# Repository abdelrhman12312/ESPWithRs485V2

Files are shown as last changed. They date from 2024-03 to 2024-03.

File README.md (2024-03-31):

# ESPWithRs485V2

you can view the pcb here in your browser 
https://kicanvas.org/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

iot master

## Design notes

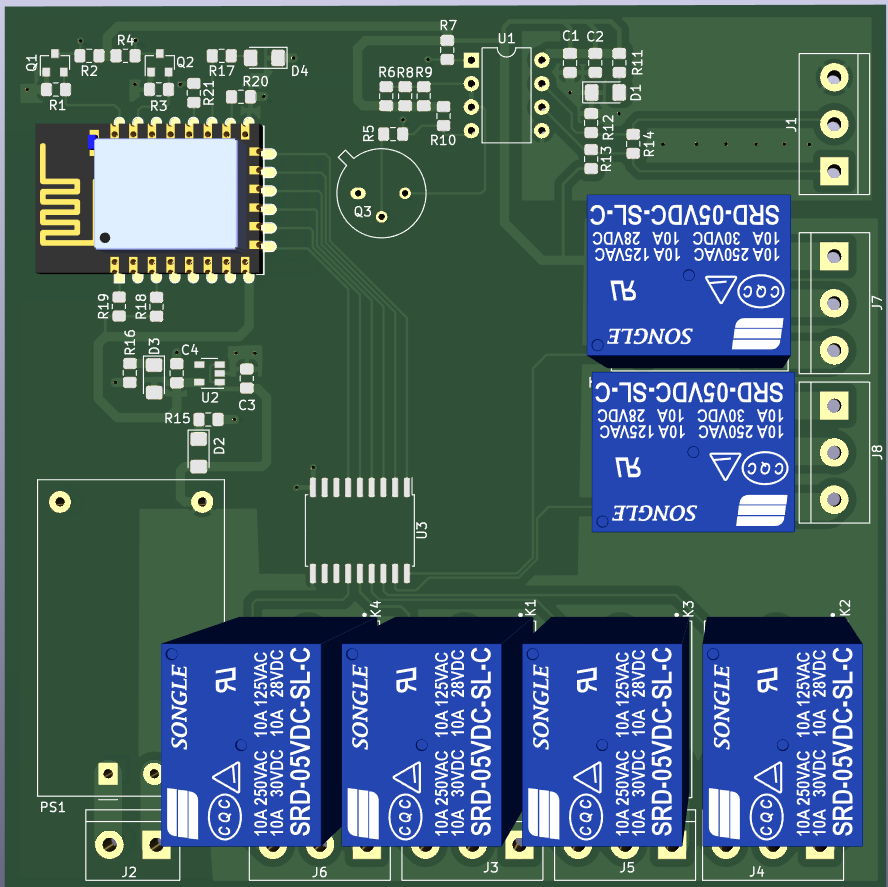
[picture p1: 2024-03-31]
iot master/png/Screenshot 2022-09-27 210828.png

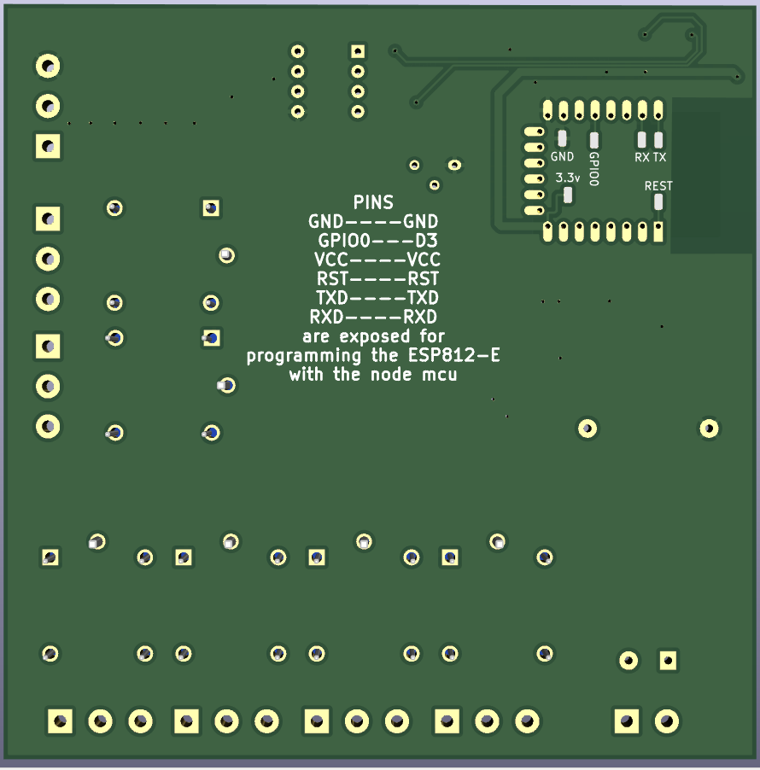
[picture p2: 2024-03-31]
iot master/png/Screenshot 2022-09-27 210906.png

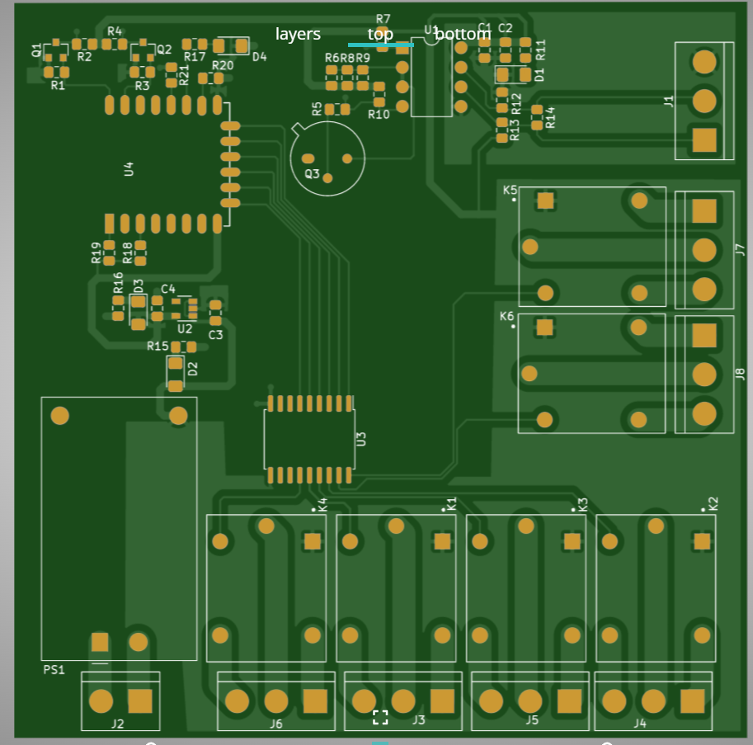
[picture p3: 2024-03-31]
iot master/png/GerberRender.png

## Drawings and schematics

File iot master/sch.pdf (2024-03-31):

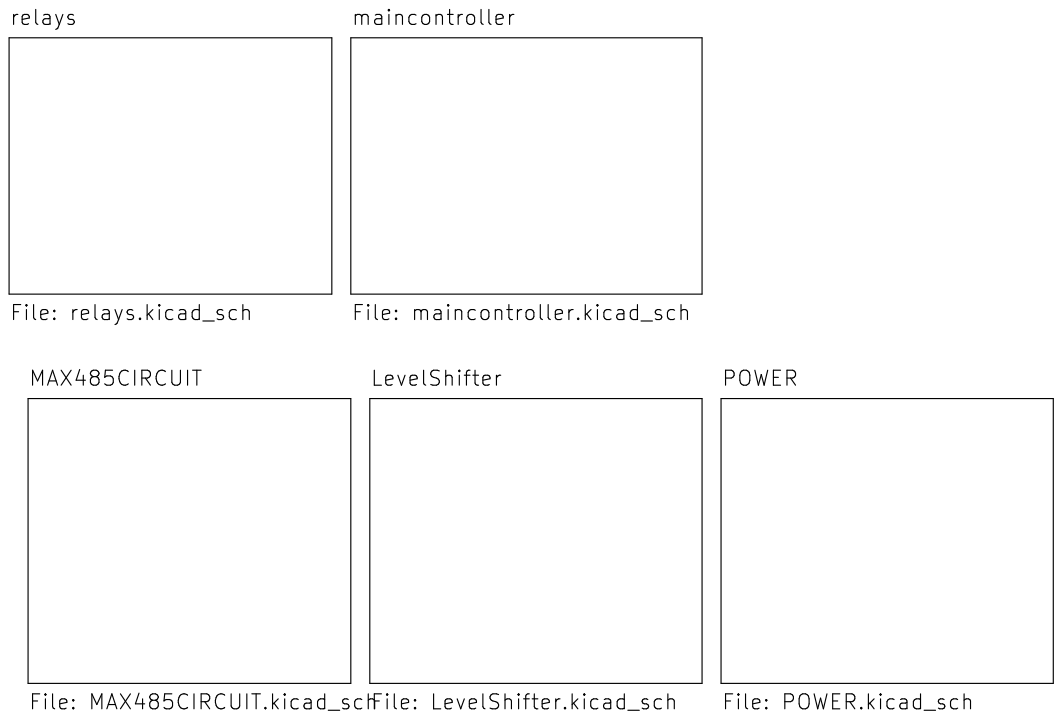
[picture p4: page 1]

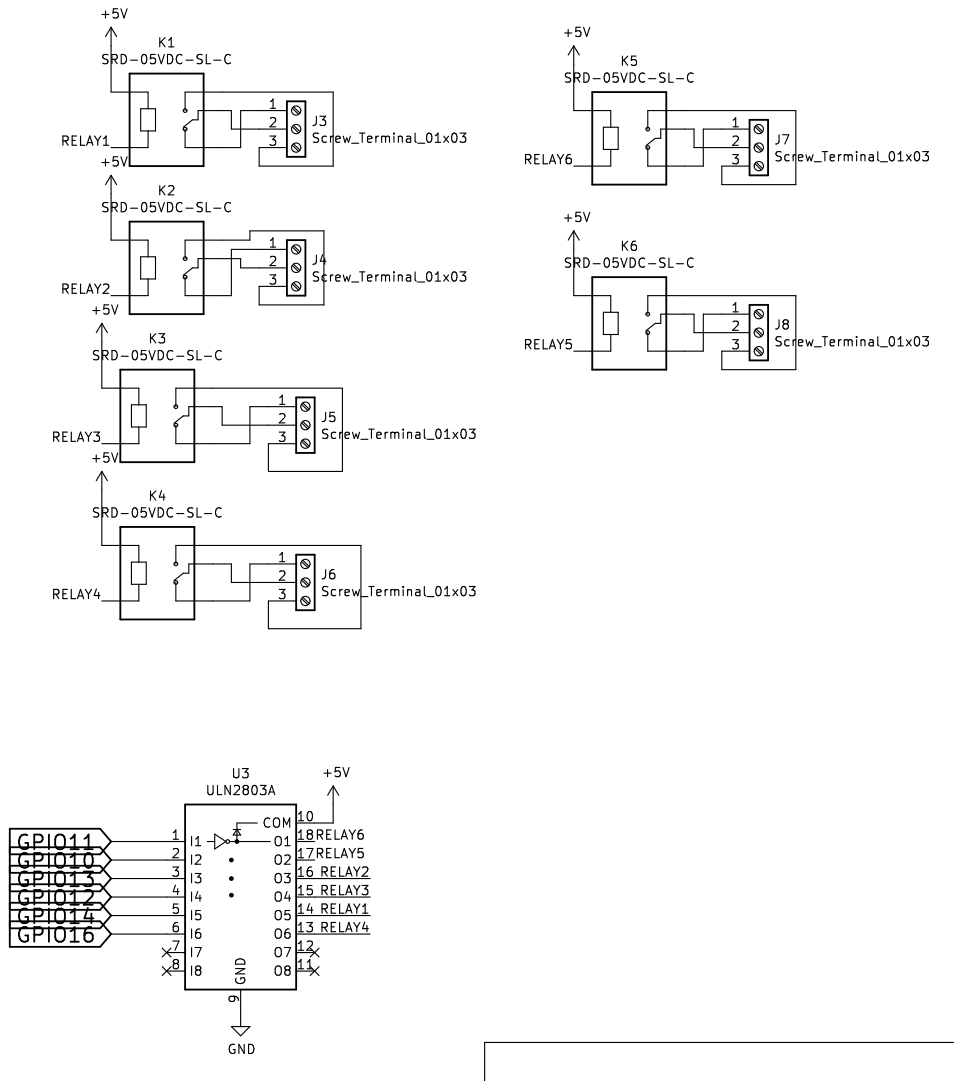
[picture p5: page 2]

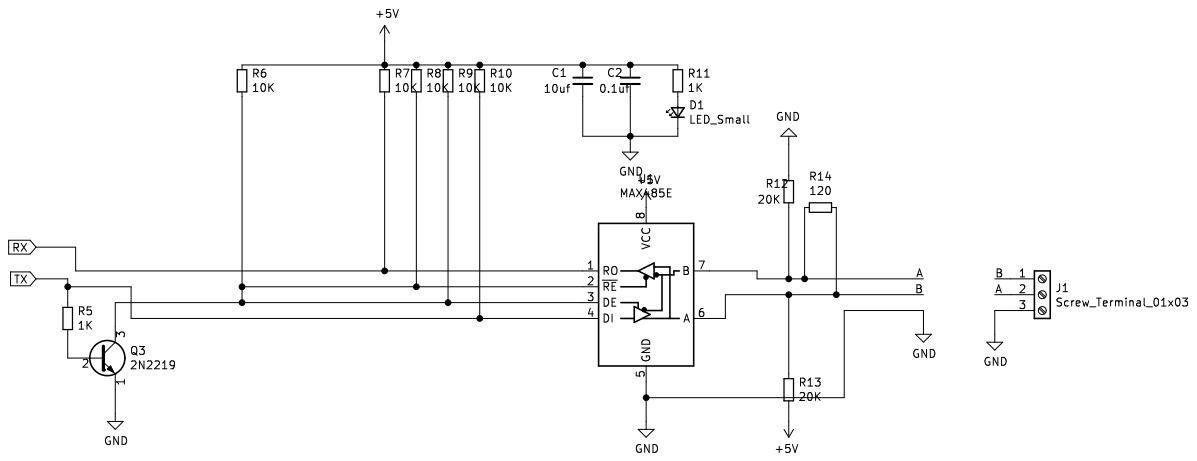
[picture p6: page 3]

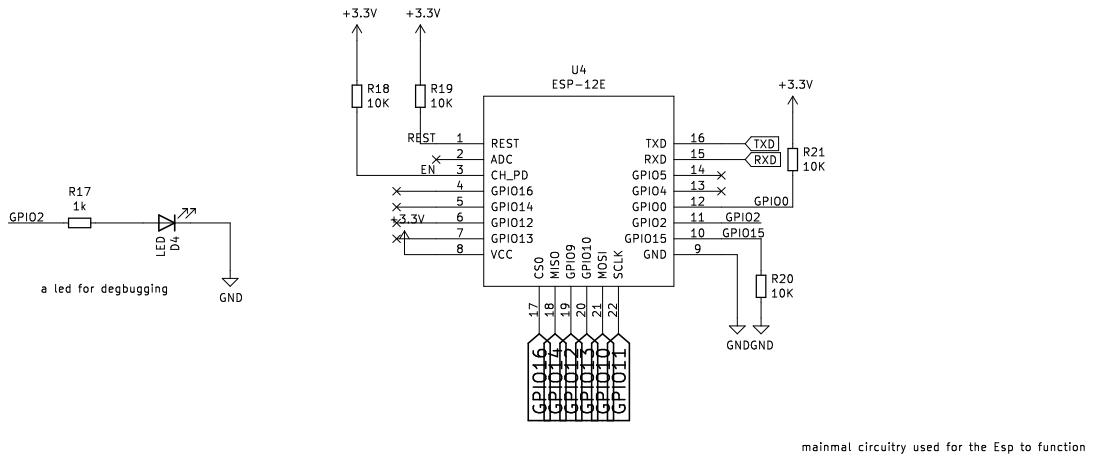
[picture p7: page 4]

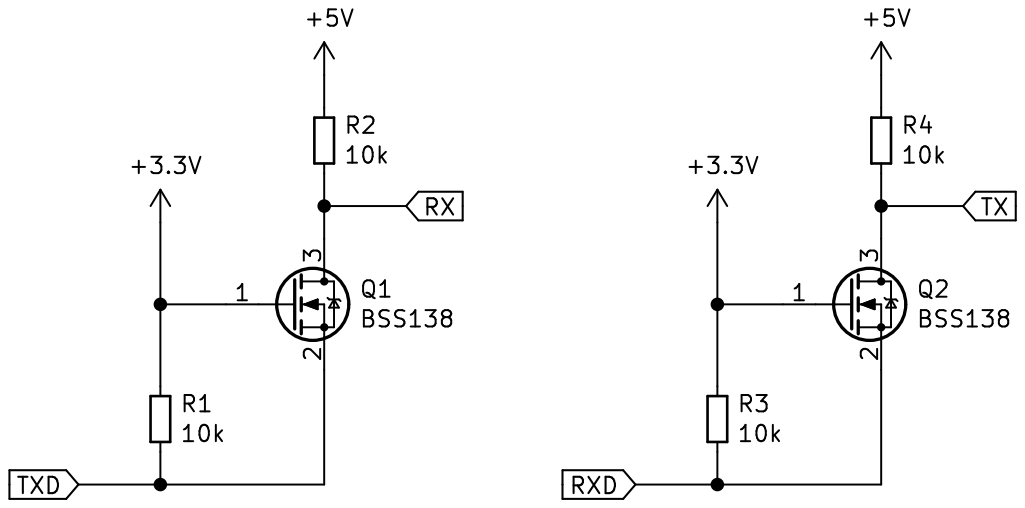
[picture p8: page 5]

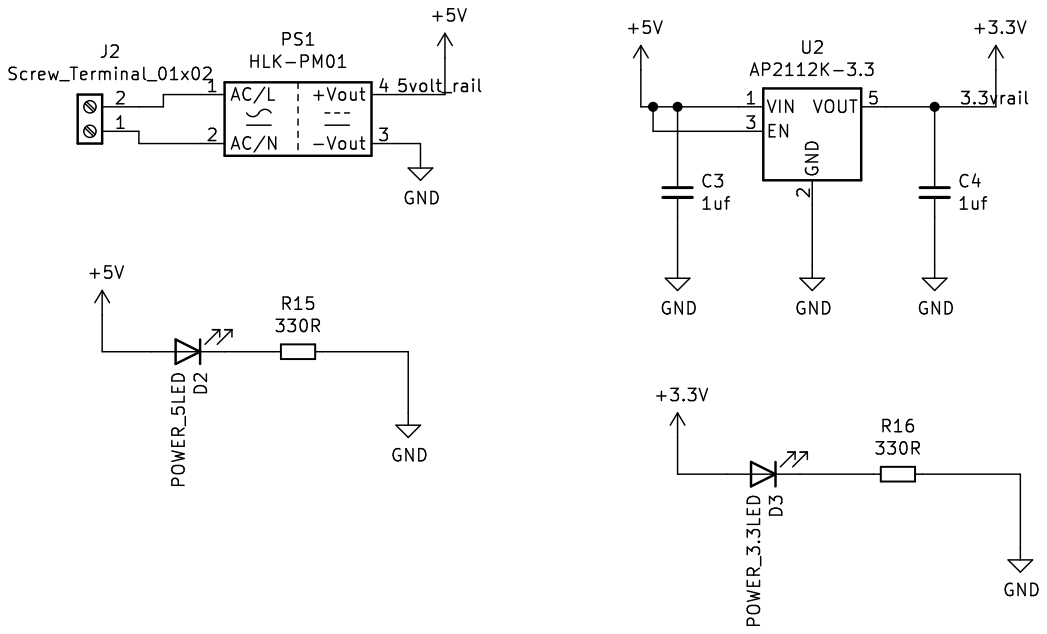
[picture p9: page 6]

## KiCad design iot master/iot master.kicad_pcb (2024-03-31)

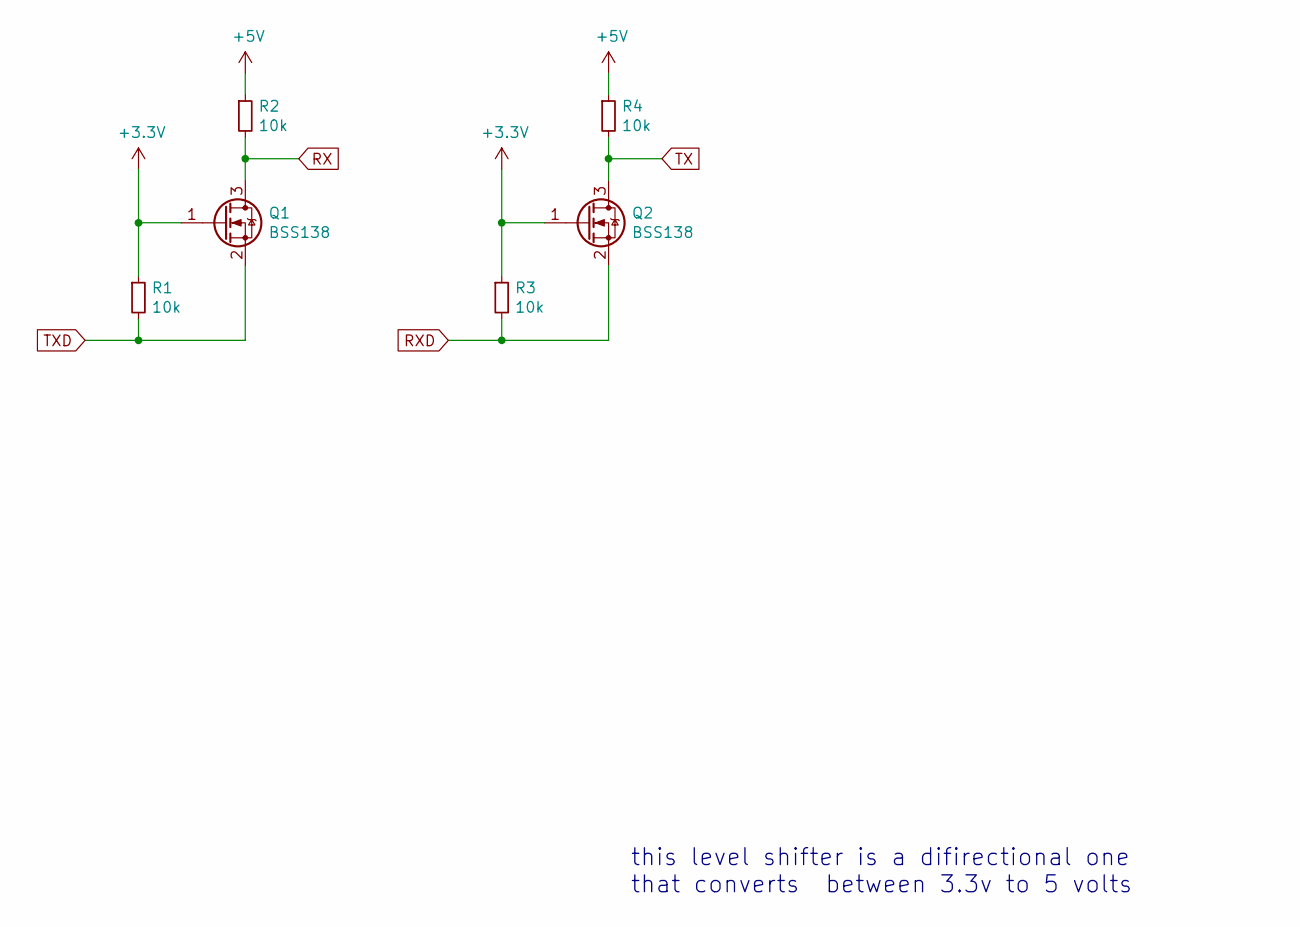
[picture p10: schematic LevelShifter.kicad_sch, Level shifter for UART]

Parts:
Q1, Q2: BSS138; SOT-23
R1, R2, R3, R4: 10k; R_0805_2012Metric_Pad1.15x1.40mm_HandSolder

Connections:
+3V3: Q1.1 (G), Q2.1 (G), R1.1, R3.1; also elsewhere on the board
+5V: R2.1, R4.1; also elsewhere on the board
RX: Q1.3 (D), R2.2; also elsewhere on the board
RXD: Q2.2 (S), R3.2; also elsewhere on the board
TX: Q2.3 (D), R4.2; also elsewhere on the board
TXD: Q1.2 (S), R1.2; also elsewhere on the board

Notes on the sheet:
this level shifter is a difirectional one that converts between 3.3v to 5 volts

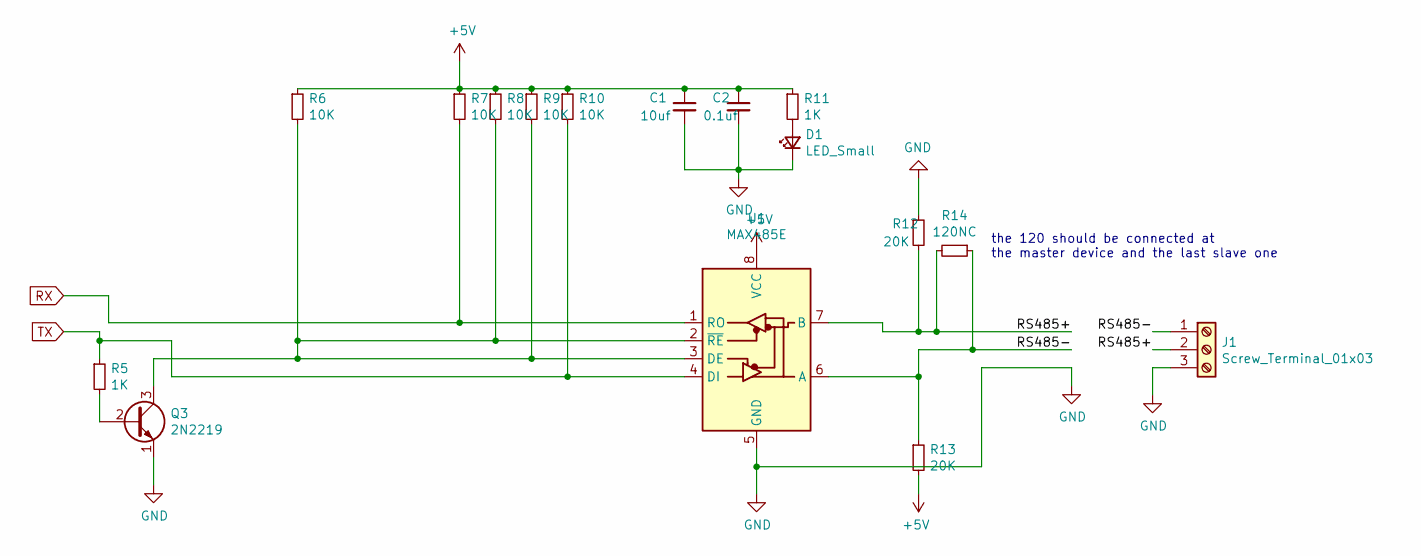
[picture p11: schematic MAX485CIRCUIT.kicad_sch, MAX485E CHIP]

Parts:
C1: 10uf; C_0805_2012Metric_Pad1.15x1.40mm_HandSolder
C2: 0.1uf; C_0805_2012Metric_Pad1.15x1.40mm_HandSolder
D1: LED_Small; LED_1206_3216Metric_Pad1.42x1.75mm_HandSolder
J1: Screw_Terminal_01x03; TerminalBlock_bornier-3_P5.08mm
Q3: 2N2219; TO-39-3
R5, R11: 1K; R_0805_2012Metric_Pad1.15x1.40mm_HandSolder
R6, R7, R8, R9, R10: 10K; R_0805_2012Metric_Pad1.15x1.40mm_HandSolder
R12, R13: 20K; R_0805_2012Metric_Pad1.15x1.40mm_HandSolder
R14: 120NC; R_0805_2012Metric_Pad1.15x1.40mm_HandSolder
U1: MAX485E; DIP-8_W7.62mm

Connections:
+5V: C1.1, C2.1, R6.1, R7.1, R8.1, R9.1, R10.1, R11.1, R13.2, U1.8 (VCC); also elsewhere on the board
/MAX485CIRCUIT/RS485+: J1.2, R12.2, R14.2, U1.7 (B)
/MAX485CIRCUIT/RS485-: J1.1, R13.1, R14.1, U1.6 (A)
GND: C1.2, C2.2, D1.1 (K), J1.3, Q3.1 (E), R12.1, U1.5 (GND); also elsewhere on the board
unnamed: D1.2 (A), R11.2
unnamed: Q3.2 (B), R5.2
unnamed: Q3.3 (C), R6.2, R8.2, R9.2, U1.2 (~RE), U1.3 (DE)
RX: R7.2, U1.1 (RO); also elsewhere on the board
TX: R5.1, R10.2, U1.4 (DI); also elsewhere on the board

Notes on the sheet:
the 120 should be connected at the master device and the last slave one

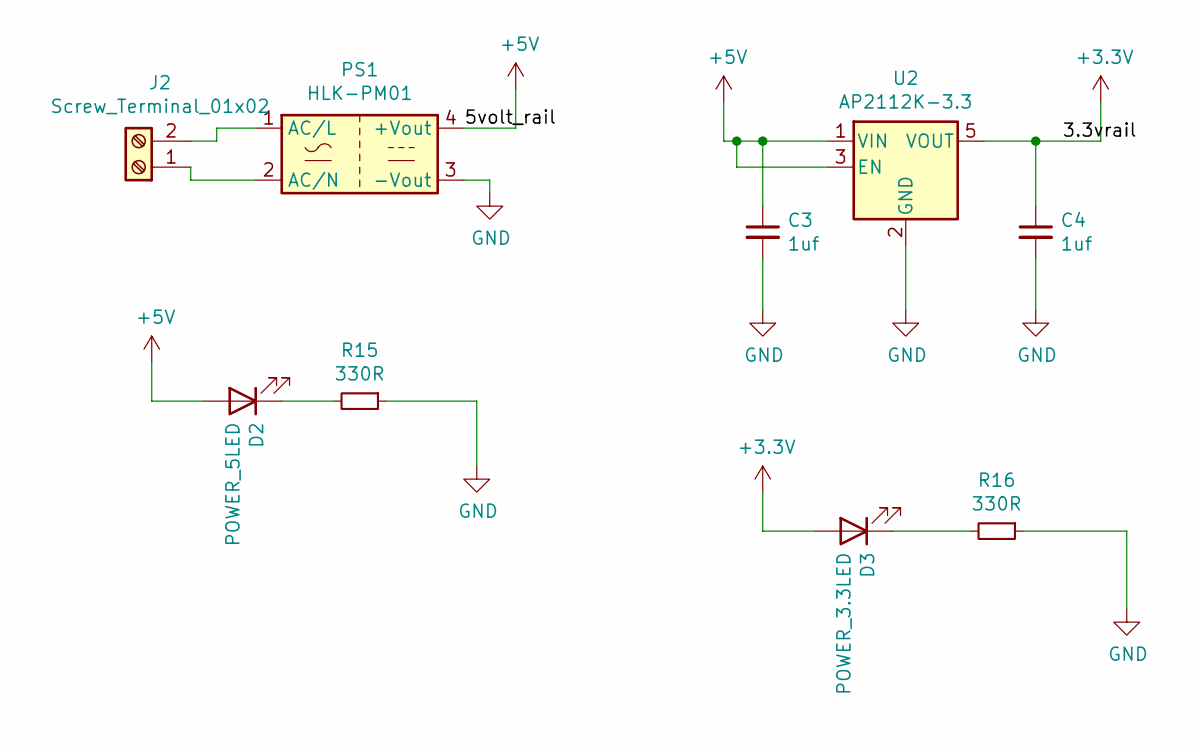
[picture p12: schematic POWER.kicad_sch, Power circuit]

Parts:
C3, C4: 1uf; R_0805_2012Metric_Pad1.15x1.40mm_HandSolder
D2: POWER_5LED; LED_1206_3216Metric_Pad1.42x1.75mm_HandSolder
D3: POWER_3.3LED; LED_1206_3216Metric_Pad1.42x1.75mm_HandSolder
J2: Screw_Terminal_01x02; TerminalBlock_bornier-2_P5.08mm
PS1: HLK-PM01; Converter_ACDC_HiLink_HLK-PMxx
R15, R16: 330R; R_0805_2012Metric_Pad1.15x1.40mm_HandSolder
U2: AP2112K-3.3; SOT-23-5

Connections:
+3V3: C4.1, D3.2 (A), U2.5 (VOUT); also elsewhere on the board
+5V: C3.1, D2.2 (A), PS1.4 (+Vout), U2.1 (VIN), U2.3 (EN); also elsewhere on the board
GND: C3.2, C4.2, PS1.3 (-Vout), R15.1, R16.1, U2.2 (GND); also elsewhere on the board
unnamed: D2.1 (K), R15.2
unnamed: D3.1 (K), R16.2
unnamed: J2.1, PS1.2 (AC/N)
unnamed: J2.2, PS1.1 (AC/L)

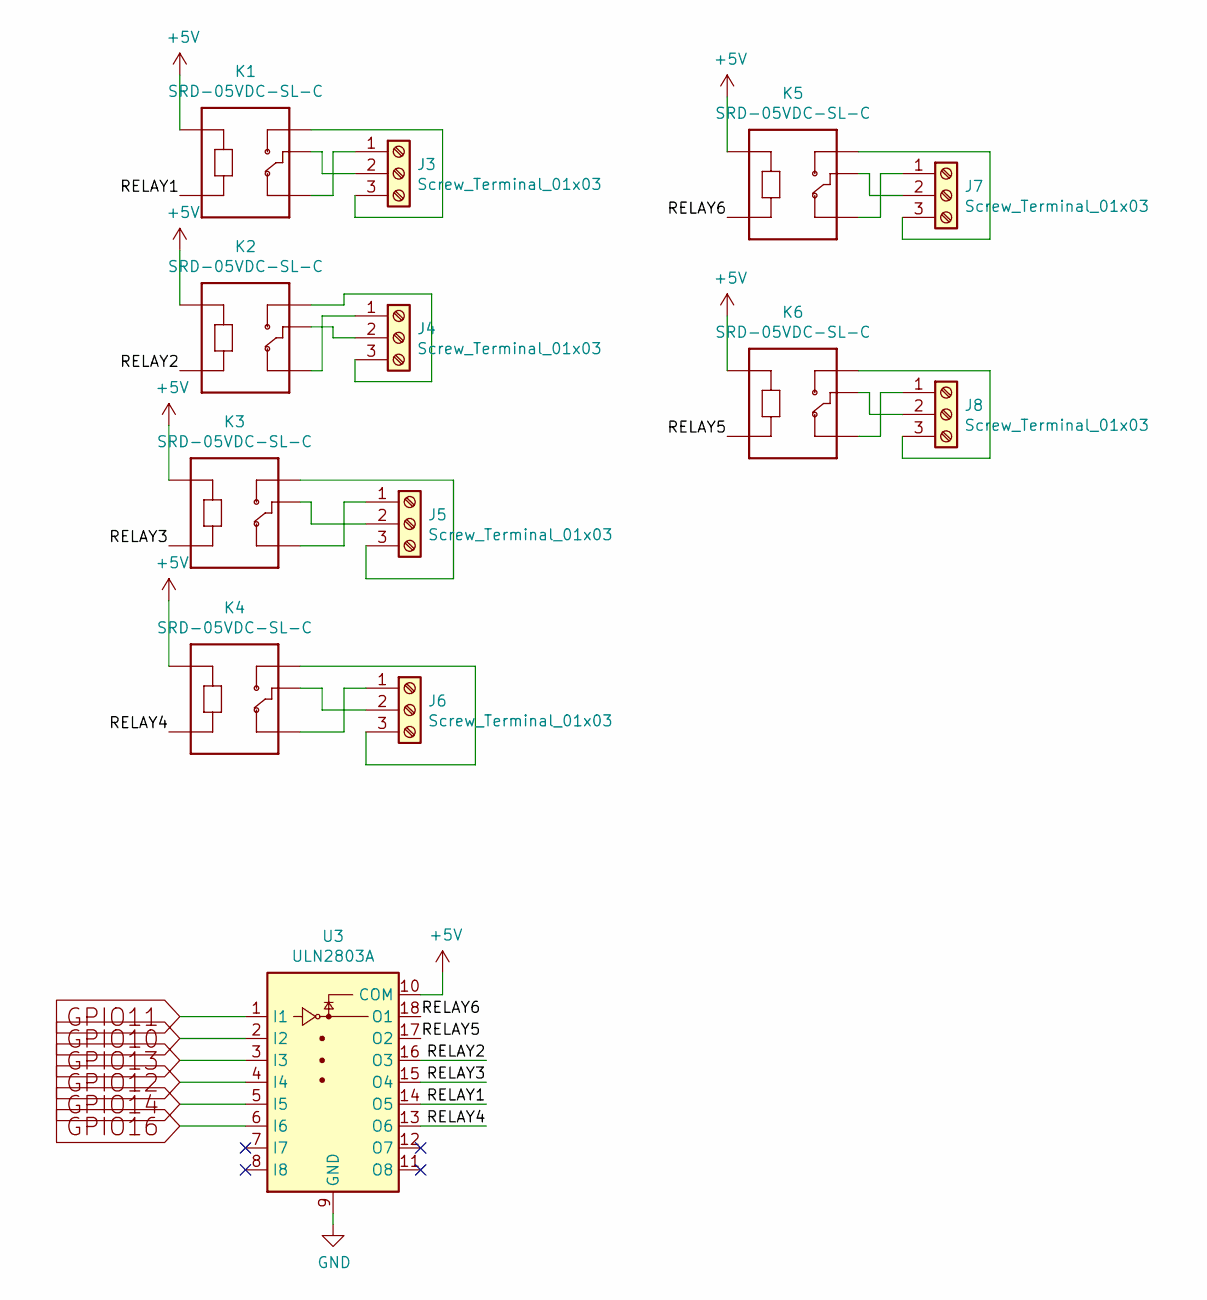
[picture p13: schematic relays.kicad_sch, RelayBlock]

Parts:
J3, J4, J5, J6, J7, J8: Screw_Terminal_01x03; TerminalBlock_bornier-3_P5.08mm
K1, K2, K3, K4, K5, K6: SRD-05VDC-SL-C; RELAY_SRD-05VDC-SL-C
U3: ULN2803A; DIP-18_W7.62mm

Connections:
+5V: K1.A1, K2.A1, K3.A1, K4.A1, K5.A1, K6.A1, U3.10 (COM); also elsewhere on the board
/relays/RELAY1: K1.A2, U3.14 (O5)
/relays/RELAY2: K2.A2, U3.16 (O3)
/relays/RELAY3: K3.A2, U3.15 (O4)
/relays/RELAY4: K4.A2, U3.13 (O6)
/relays/RELAY5: K6.A2, U3.17 (O2)
/relays/RELAY6: K5.A2, U3.18 (O1)
GND: U3.9 (GND); also elsewhere on the board
GPIO10: U3.2 (I2); also elsewhere on the board
GPIO11: U3.1 (I1); also elsewhere on the board
GPIO12: U3.4 (I4); also elsewhere on the board
GPIO13: U3.3 (I3); also elsewhere on the board
GPIO14: U3.5 (I5); also elsewhere on the board
GPIO16: U3.6 (I6); also elsewhere on the board
unnamed: J3.1, K1.NC
unnamed: J3.2, K1.COM
unnamed: J3.3, K1.NO
unnamed: J4.1, K2.NC
unnamed: J4.2, K2.COM
unnamed: J4.3, K2.NO
unnamed: J5.1, K3.NC
unnamed: J5.2, K3.COM
unnamed: J5.3, K3.NO
unnamed: J6.1, K4.NC
unnamed: J6.2, K4.COM
unnamed: J6.3, K4.NO
unnamed: J7.1, K5.NC
unnamed: J7.2, K5.COM
unnamed: J7.3, K5.NO
unnamed: J8.1, K6.NC
unnamed: J8.2, K6.COM
unnamed: J8.3, K6.NO

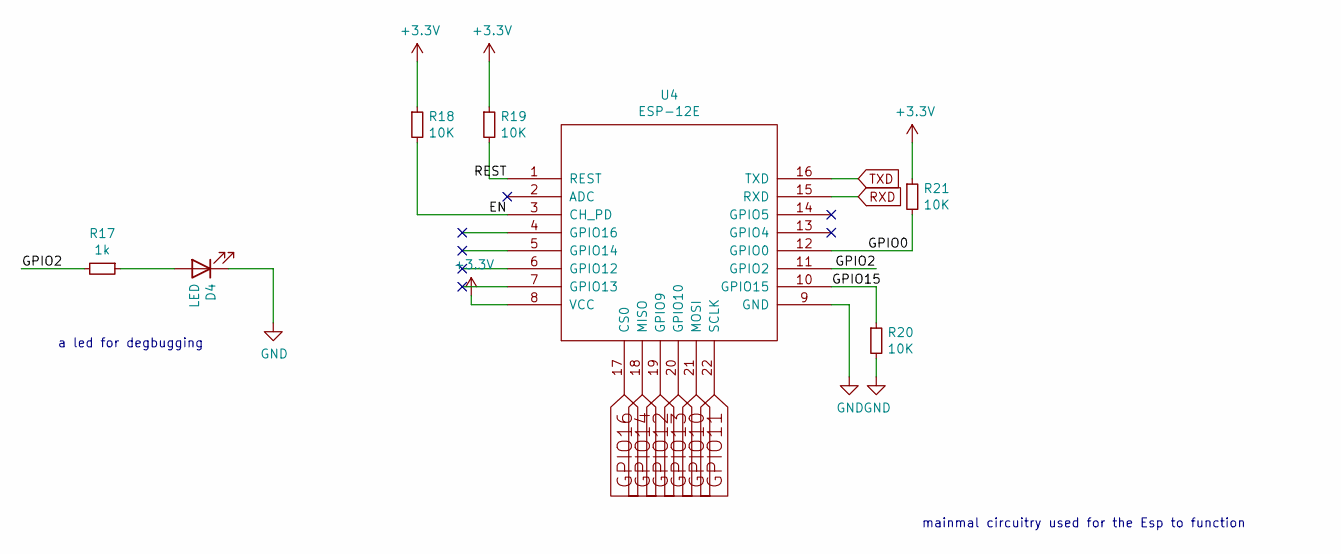
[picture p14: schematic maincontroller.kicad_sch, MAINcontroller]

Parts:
D4: LED; LED_1206_3216Metric_Pad1.42x1.75mm_HandSolder
R17: 1k; R_0805_2012Metric_Pad1.15x1.40mm_HandSolder
R18, R19, R20, R21: 10K; R_0805_2012Metric_Pad1.15x1.40mm_HandSolder
U4: ESP-12E

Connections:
+3V3: R18.1, R19.1, R21.1, U4.8 (VCC); also elsewhere on the board
/maincontroller/EN: R18.2, U4.3 (CH_PD)
/maincontroller/GPIO0: R21.2, U4.12 (GPIO0); also elsewhere on the board
/maincontroller/GPIO2: R17.2, U4.11 (GPIO2)
/maincontroller/GPIO15: R20.1, U4.10 (GPIO15)
/maincontroller/REST: R19.2, U4.1 (REST); also elsewhere on the board
GND: D4.1 (K), R20.2, U4.9 (GND); also elsewhere on the board
GPIO10: U4.21 (MOSI); also elsewhere on the board
GPIO11: U4.22 (SCLK); also elsewhere on the board
GPIO12: U4.19 (GPIO9); also elsewhere on the board
GPIO13: U4.20 (GPIO10); also elsewhere on the board
GPIO14: U4.18 (MISO); also elsewhere on the board
GPIO16: U4.17 (CS0); also elsewhere on the board
unnamed: D4.2 (A), R17.1
RXD: U4.15 (RXD); also elsewhere on the board
TXD: U4.16 (TXD); also elsewhere on the board

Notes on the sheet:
a led for degbugging
mainmal circuitry used for the Esp to function

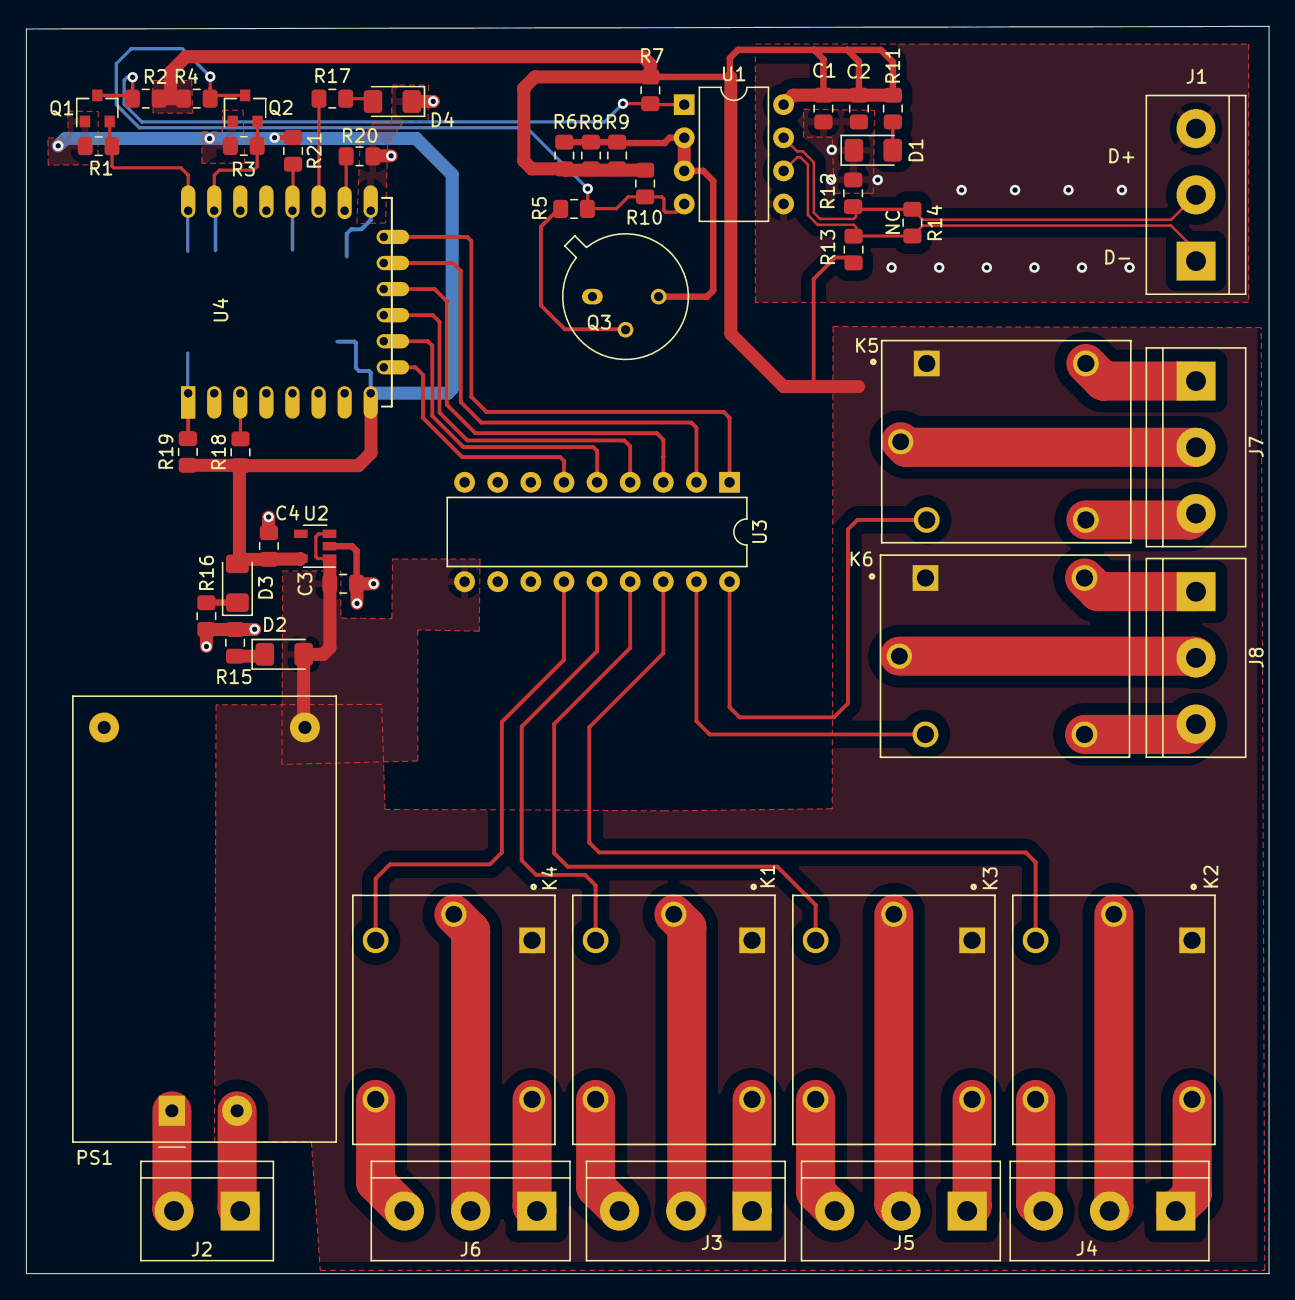
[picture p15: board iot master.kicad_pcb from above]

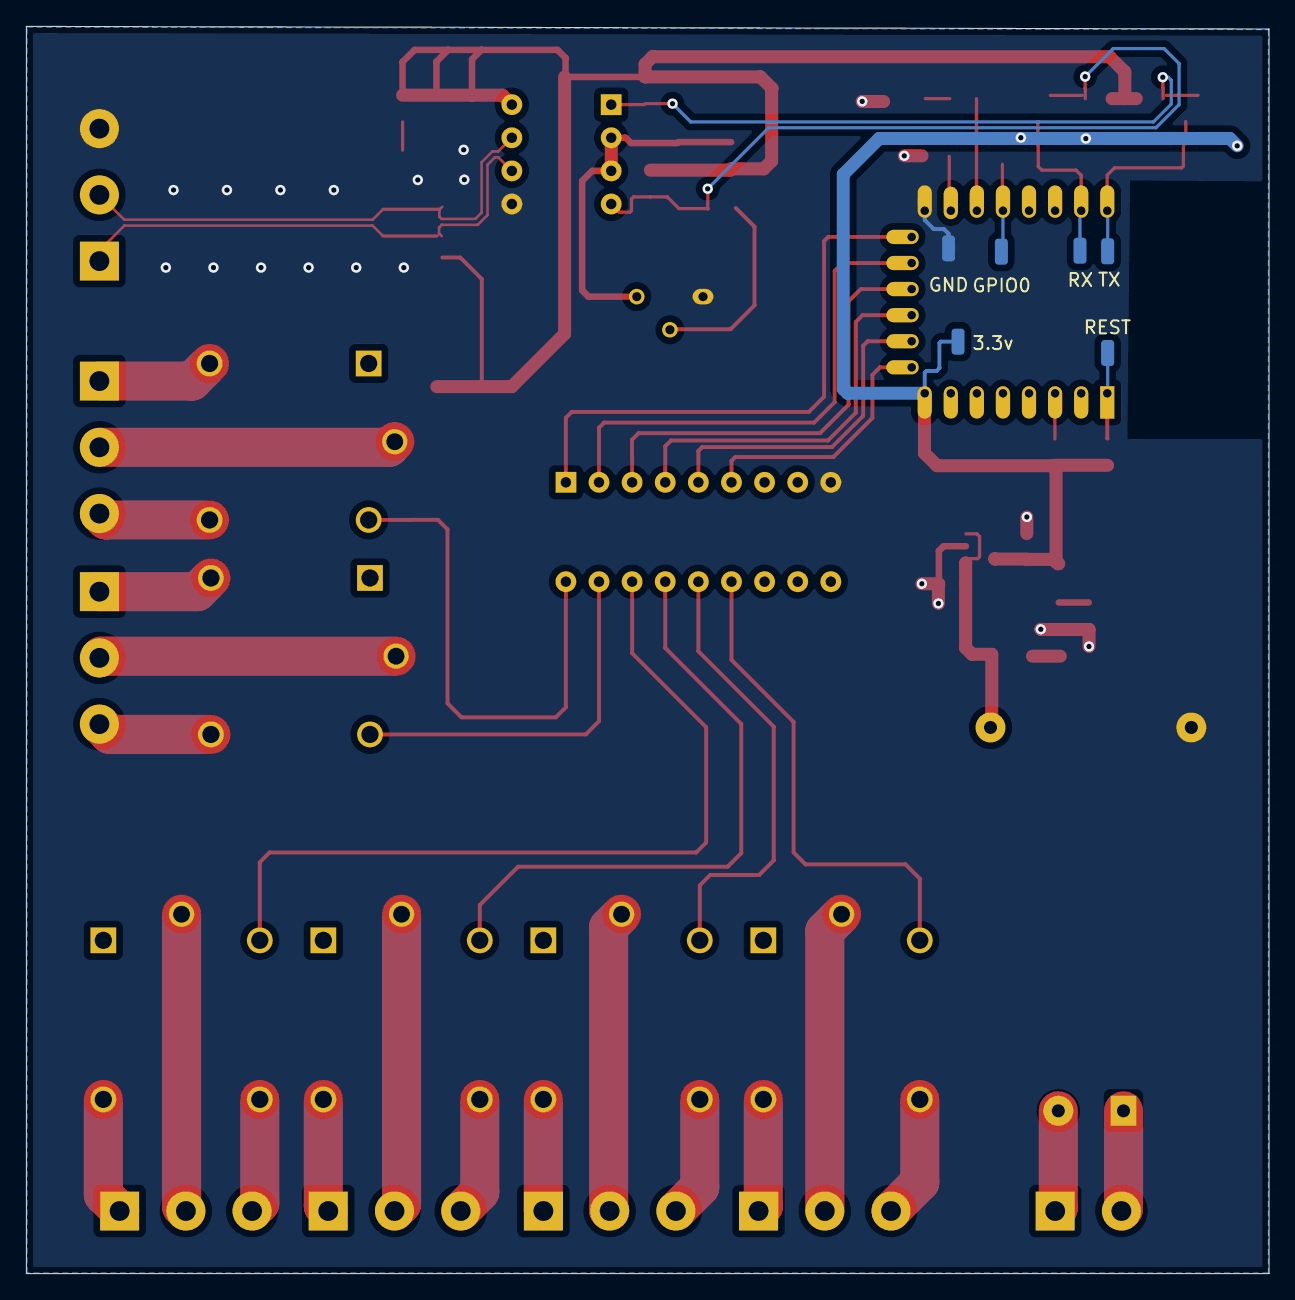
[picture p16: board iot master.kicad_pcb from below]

Board: 2 copper layers, 95.3 x 95.7 mm, 57 parts (6 on the bottom side), 52 nets.

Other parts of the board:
3.3v: SolderWirePad_1x01_SMD_1x2mm
GND: SolderWirePad_1x01_SMD_1x2mm
GPIO0: SolderWirePad_1x01_SMD_1x2mm
REST: SolderWirePad_1x01_SMD_1x2mm
RX: SolderWirePad_1x01_SMD_1x2mm
TX: SolderWirePad_1x01_SMD_1x2mm

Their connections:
+3V3: 3.3v.1; also elsewhere on the board
/maincontroller/GPIO0: GPIO0.1; also elsewhere on the board
/maincontroller/REST: REST.1; also elsewhere on the board
RXD: RX.1; also elsewhere on the board
TXD: TX.1; also elsewhere on the board
